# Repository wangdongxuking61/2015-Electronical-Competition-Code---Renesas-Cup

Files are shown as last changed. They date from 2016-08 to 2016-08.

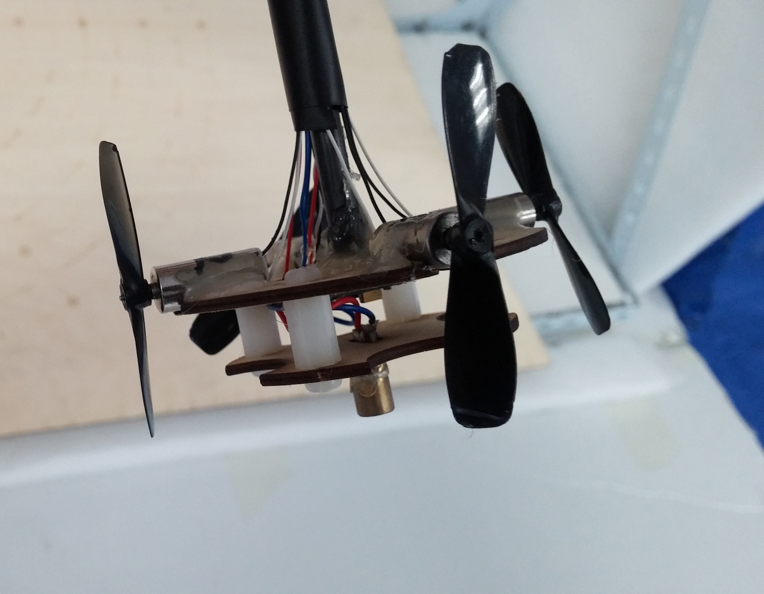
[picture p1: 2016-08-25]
pictures/CAM00127.jpg

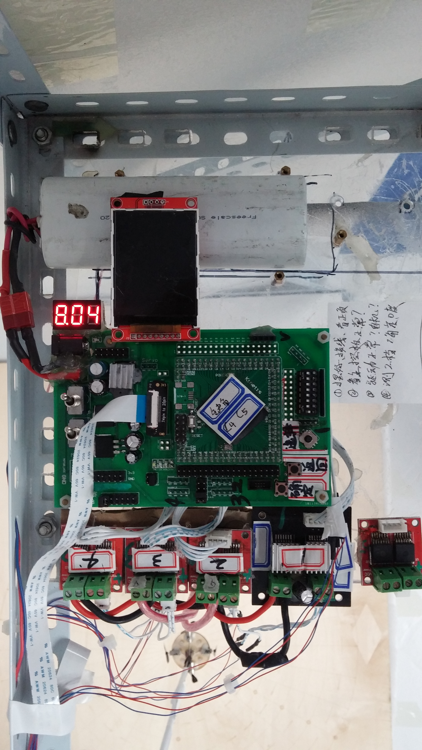
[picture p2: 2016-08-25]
pictures/CAM00123.jpg

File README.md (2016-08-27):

# 2015年全国大学生电子设计竞赛“瑞萨杯”队伍开源硬件&代码<p>

### 作品简介
* 捧杯题目：B题风力摆<p>
* 捧杯学校：大连理工大学<p>
* 总结帖：http://www.znczz.com/thread-237701-1-1.html<p>
* 作品展示视频：http://v.youku.com/v_show/id_XMTY5OTcxODE1Mg==.html?beta&<p>
* 谈情怀、技术、公平性等撕逼话题，请转：http://www.znczz.com/thread-105261-1-1.html<p>
* 硬件组成：K60单片机、MPU6050、空心杯电机、BTS79XX系列驱动芯片、山外（原鹰眼）二值化摄像头等<p>

### 目录简介<p>
* 2015-Electronical-Competition-Code：比赛代码工程，使用IAR7.3打开<p>
* 2015 Electronical Competition Hardware Board：比赛硬件工程，含原理图和PCB，使用Altium Designer2014打开<p>
* CAD：使用激光雕刻机制作的托盘支架等部件工程图，使用AutoCAD打开<p>
* 相关资料：相关介绍资料和器件资料<p>
* pictures：作品的一些照片<p>
* 风力摆控制系统(B题)2015电子设计大赛.pdf：赛题B题目要求<p>
* 2015电赛瑞萨杯-B题经验总结-王东旭.pdf：赛后总结，执笔人王东旭<p>

### 上位机<p>
* 做关于硬件的比赛肯定少不了上位机的辅助，然而一个好的上位机简直是利器<p>
* 智能车超好用上位机推荐(附C#教程)：http://www.znczz.com/thread-237704-1-1.html<p>
* 自己开发的上位机源码：https://github.com/wangdongxuking61/C-sharp_PC2MCU_Draw<p>

### 执笔人简介（欢迎技术交流）：<p>
* 本硕学校：大连理工&国防科大<p>
* wechat：wangdongxuking61<p>
* 擅长&爱好：C/C++、硬件、SDN、摄影<p>

### 有空完善完善...<p>

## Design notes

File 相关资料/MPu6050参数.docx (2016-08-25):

Mpu6050为全球首例整合3轴陀螺仪、3轴加速器、含9轴融合演；MPU-6000为全球首例整合性6轴运动处理组件，相较于多组件方案，免除了组合陀螺仪与加速器时之轴间差的问题，减少了大量的包装空间。MPU-6000整合了3轴陀螺仪、3轴加速器，并含可藉由第二个I2C端口连接其他厂牌之加速器、磁力传感器、或其他传感器的数位运动处理(DMP: Digital Motion Processor)硬件加速引擎，由主要I2C端口以单一数据流的形式，向应用端输出完整的9轴融合演算技术InvenSense的运动处理资料库，可处理运动感测的复杂数据，降低了运动处理运算对操作系统的负荷，并为应用开发提供架构化的API。
MPU-6000的角速度全格感测范围为±250、±500、±1000与±2000°/sec (dps)，可准确追緃快速与慢速动作，并且，用户可程式控制的加速器全格感测范围为±2g、±4g±8g与±16g。产品传输可透过最高至400kHz的I2C或最高达20MHz的SPI。

MPU-6000可在不同电压下工作，VDD供电电压介为2.5V±5%、3.0V±5%或3.3V±5%，逻辑接口VVDIO供电为1.8V± 5%。MPU-6000的包装尺寸4x4x0.9mm(QFN)，在业界是革命性的尺寸。其他的特征包含内建的温度感测器、包含在运作环境中仅有±1%变动的振荡器。

应用：运动感测游戏；现实增强；电子稳像 (EIS: Electronic Image Stabilization)
　　　　　 光学稳像(OIS: Optical Image Stabilization)；行人导航器；“零触控”手势用户接口；姿势快捷方式
认证市场：智能型手机；平板装置设备；手持型游戏产品；游戏机；3D遥控器；可携式导航设备
特征
　　1、以数字输出6轴或9轴的旋转矩阵、四元数(quaternion)、欧拉角格式(Euler Angle forma)的融合演算数据。
　　2、具有131 LSBs/°/sec 敏感度与全格感测范围为±250、±500、±1000与±2000°/sec 的3轴角速度感测器(陀螺仪)。
　　3、可程式控制，且程式控制范围为±2g、±4g、±8g和±16g的3轴加速器。
　　4、移除加速器与陀螺仪轴间敏感度，降低设定给予的影响与感测器的飘移。
　　5、数字运动处理(DMP: Digital Motion Processing)引擎可减少复杂的融合演算数据、感测器同步化、姿势感应等的负荷。
　　6、运动处理数据库支持Android、Linux与Windows
　　7、内建之运作时间偏差与磁力感测器校正演算技术，免除了客户须另外进行校正的需求。
　　8、以数位输出的温度传感器
　　9、以数位输入的同步引脚(Sync pin)支援视频电子影相稳定技术与GPS
　　10、可程式控制的中断(interrupt)支援姿势识别、摇摄、画面放大缩小、滚动、快速下降中断、high-G中断、零动作感应、触击感应、摇动感应功能。
　　11、VDD供电电压为2.5V±5%、3.0V±5%、3.3V±5%；VDDIO为1.8V± 5%
　　12、陀螺仪运作电流：5mA，陀螺仪待命电流：8A；加速器运作电流：8A，加速器省电模式电流： 8A@10Hz
　　13、高达400kHz快速模式的I2C，或最高至20MHz的SPI串行主机接口(serial host interface)
　　14、内建频率产生器在所有温度范围(full temperature range)仅有±1%频率变化。
　　15、使用者亲自测试
　　16、10,000 g 碰撞容忍度
　　17、为可携式产品量身订作的最小最薄包装 (4x4x0.9mm QFN)
　　18、符合RoHS及环境标准MPU-6000为全球首例整合性6轴运动处理组件，相较于多组件方案，免除了组合陀螺仪与加速器时之轴间差的问题，减少了大量的包装空间。MPU-6000整合了3轴陀螺仪、3轴加速器，并含可藉由第二个I2C端口连接其他厂牌之加速器、磁力传感器、或其他传感器的数位运动处理(DMP: Digital Motion Processor)硬件加速引擎，由主要I2C端口以单一数据流的形式，向应用端输出完整的9轴融合

演算技术：InvenSense的运动处理资料库，可处理运动感测的复杂数据，降低了运动处理运算对操作系统的负荷，并为应用开发提供架构化的API。
　从MPU6050的技术文档里我们可以看得出来一些重要参数出来！如果比例数是多少，芯片的特性都是可以看得出来的！

第一张是MPU6000与MPU6050芯片的比较！

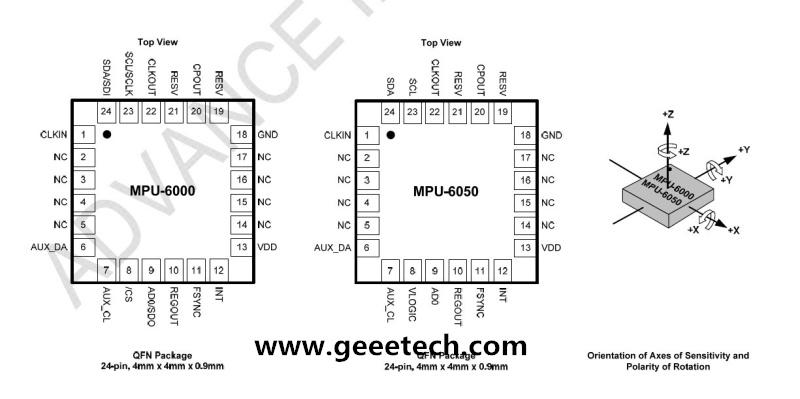
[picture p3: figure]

第二张是MPU6000与MPU6050芯片的最小驱动电路的连接!

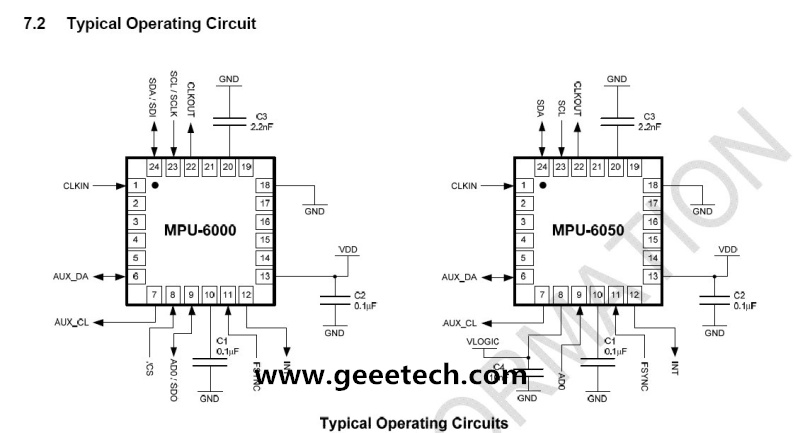
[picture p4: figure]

第三张是陀螺仪的设计规范表格！

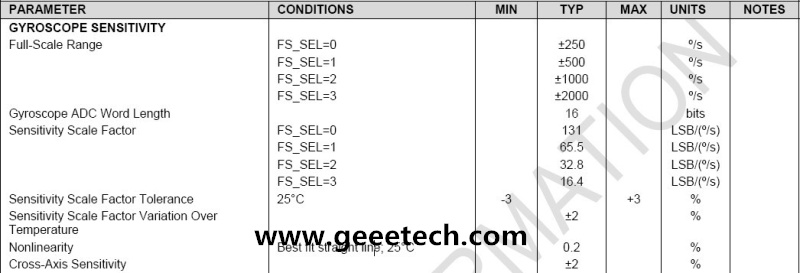
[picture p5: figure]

第四张是加速度的设计规范表格！

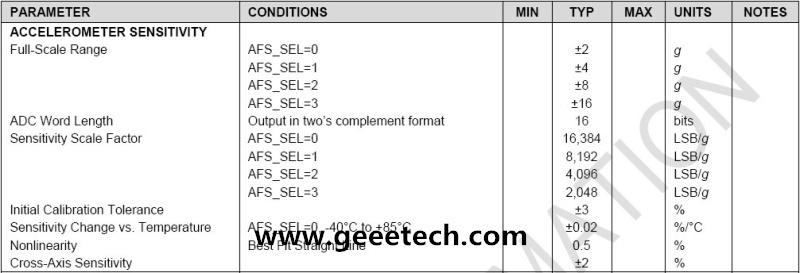
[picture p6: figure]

下面是arduino与MPU6050的小模块的连线图：
　　A4接SDA A5接SCL vcc接3v3商家说可以接5v但是保守起见还是接了3.3v GND接GND不过mpu受温度的影响精度相差比较大！
　　注意：本模块采用的是IIC通信方式，所以我们只需要连接四跟线就可以完成电路的连接，简单方便！
1.关于6050 陀螺仪和加速度计 的角速度和角度计算。
　　A.陀螺仪角度计算，很多帖子中都提到了用的是积分，但是我这里还是重新讲下。
　　　　　　angle_n = angle_n-1 + (Gyro-C_Gyro)*R_Gyro;
　　　　　　　　（1）angle_n 当前角度值，它的单位是度（°）
　　　　　　　　（2）angle_n-1 上一次计算出的角度值
　　　　　　　　（3）Gyro 陀螺仪敏感轴偏转值，也就是当前敏感轴读数
　　　　　　　　（4）C_Gyro 陀螺仪零点偏移值，这个值的测量方法是：将陀螺仪敏感轴水平放置静止时的读数，我的零点偏移值是水平、垂直、倒置，分别取1024次，作平均值得出的，读数是-177.8865041，但是最后在程序实践中，调整到-99.90。或许还有别的办法，自己看着办吧。
　　　　　　　　（5）R_Gyro 是陀螺仪比例。飞思卡尔的参考中提到这个值是可以计算出来的，下面我会提供下载，大家自己去看看怎么算的，但是在其论坛和调试手册中都提到，这个比例值还是实验法测量出来的比较准确。
B.加速度仪 角度计算。
　　 加速度仪的角度计算有很多方法，论坛里就有2中。但是都用到了三角函数，数学没学好，照抄了也不行。参考了飞思卡尔的计算方法后大概是这样的。
Angle_Z = (az-C_Z)*R_Z;
　　　　　　　　 （1）angle_z 加速度计敏感轴Z轴产生倾角计算出的角度，单位度（°）
　　　　　　　　 （2）az 是加速度仪 Z轴读数
　　　　　　　　 （3）C_Z Z轴零点偏移量 测量方法和陀螺仪的一样。
　　　　　　　　 （4）R_Z 加速度计Z轴比例
　　C.反复试验，MPU6050加速度计Z轴对应的是陀螺仪的X轴。不知道是不是我的有问题，还是就这么设计的？

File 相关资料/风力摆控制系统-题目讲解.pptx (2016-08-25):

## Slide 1

电子设计竞赛
控制类题目讲解

## 1、全国电子设计竞赛简介 2、控制类题目注意事项 3、2015年风力摆控制系统——硬件 4、2015年风力摆控制系统——机械 5、2015年风力摆控制系统——软件

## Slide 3

全国电子设计竞赛简介

- 大学生重点赛事
- 两年一届
- “半封闭，相对集中”的比赛方式
- 为期4天（第一天8:00 ~ 第四天20:00）
- 提交竞赛报告

东北赛区赛
综合测评
全国复测

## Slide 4

控制类题目注意事项

1、赛前准备
硬件：
  - 主控板（含有所有功能）
  - 驱动模块（BTS即可）
  - 传感器（加速度计，陀螺仪，绝对编码器，相对编码器， 霍尔测速传感器，CCD，摄像头，光电管，等等）
  - 蓝牙模块（至少一对）
  - 显示屏
  - 电机
  - 官网提供主要元器件清单（猜题目）
  - 个人备用元件
软件：
  - UI
  - 对应硬件的软件（电机驱动、传感器驱动、测速，等等）
2、认真审题（第一天）
3、确定方案（多测试）

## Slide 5

风力摆控制系统——硬件

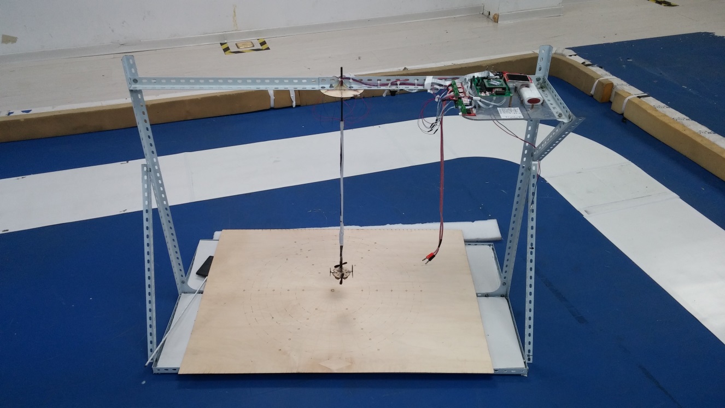
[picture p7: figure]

风力摆控制系统

主控芯片K60

显示屏

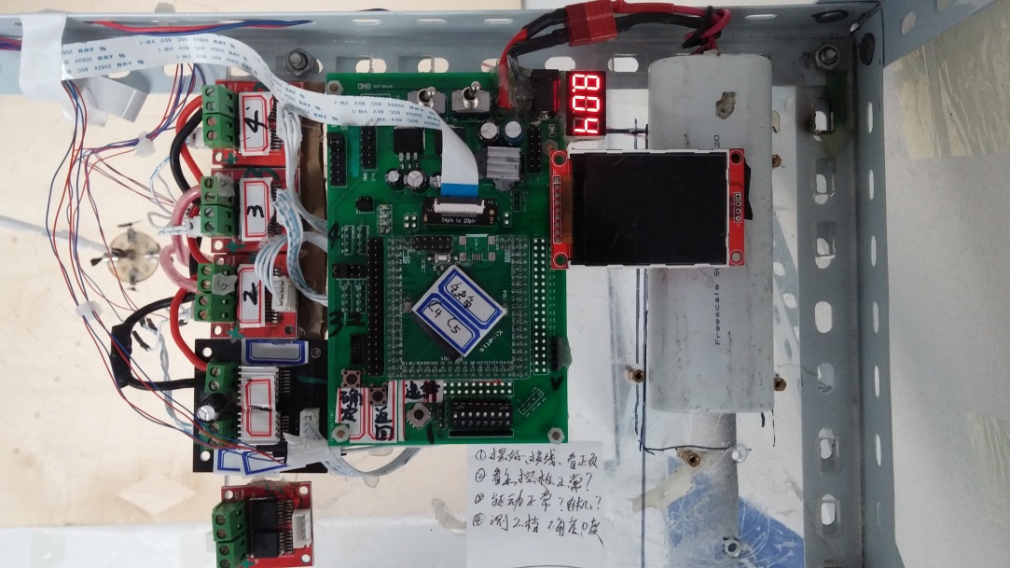
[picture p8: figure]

四路驱动模块

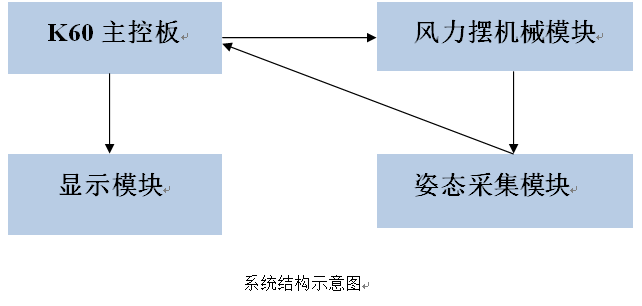
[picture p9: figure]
屏幕剪辑

主控板

备用驱动模块

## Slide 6

风力摆控制系统——硬件

主控芯片方案 ——飞思卡尔K60
电源方案 ——LM2596 (5v)，AMS1117(3v)
驱动方案 ——BTN7971
电机方案 ——四轴空心杯电机
传感器方案 ——陀螺仪加速度计MPU6050

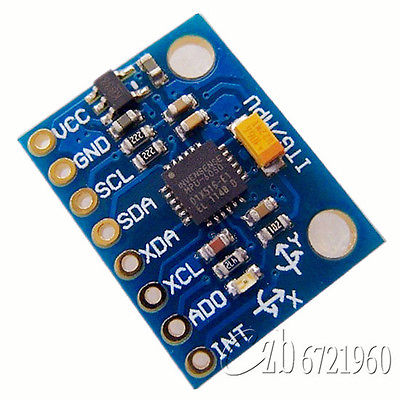
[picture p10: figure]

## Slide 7

风力摆控制系统——机械

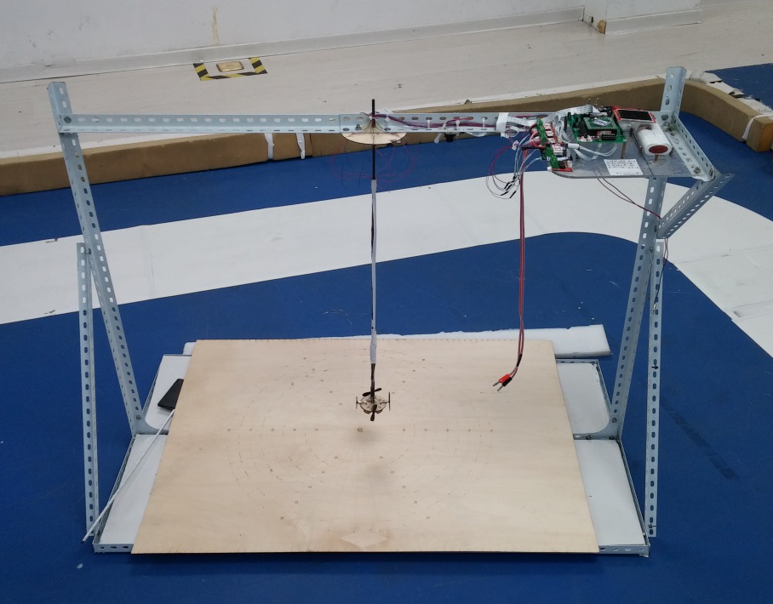
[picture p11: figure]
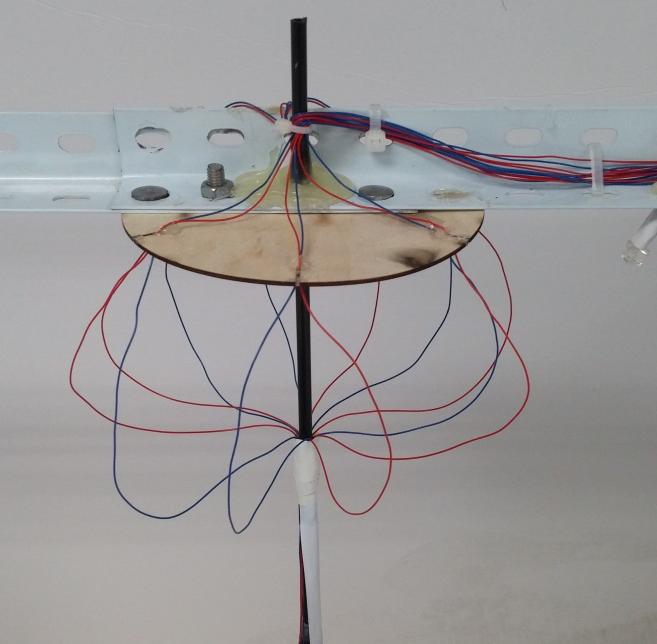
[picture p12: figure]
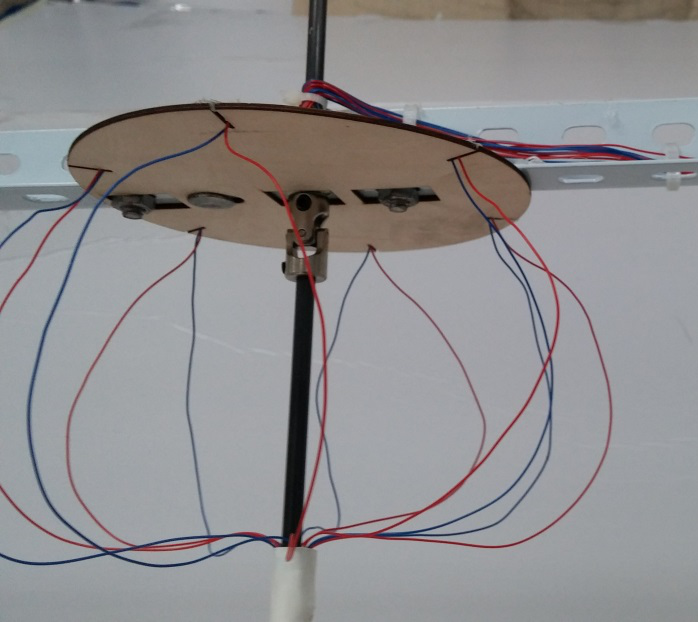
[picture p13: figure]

细导线
——减少外力对摆的干扰
导线托盘
——使摆的受力均匀

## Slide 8

风力摆控制系统——机械

风力摆摆头

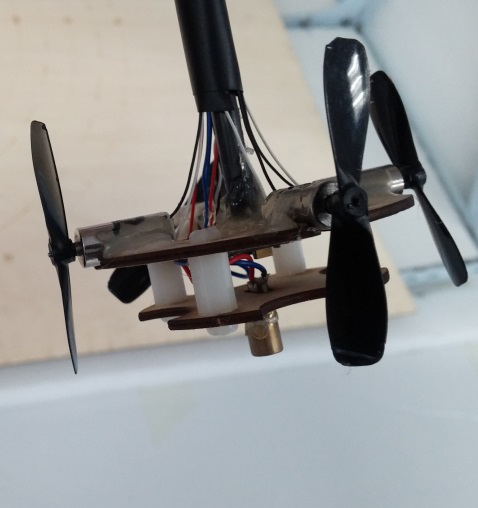
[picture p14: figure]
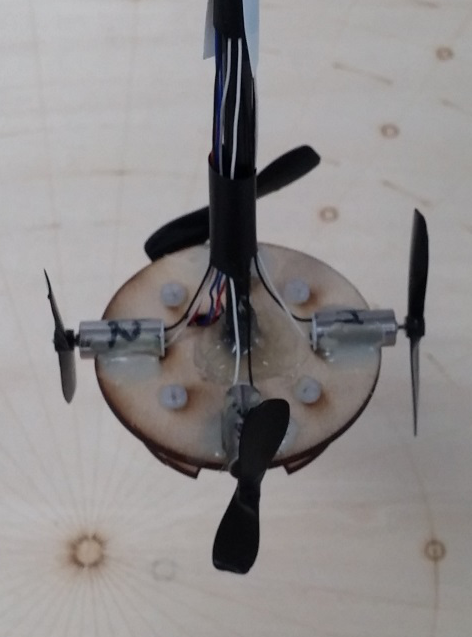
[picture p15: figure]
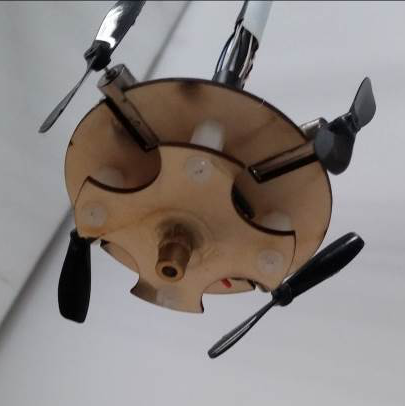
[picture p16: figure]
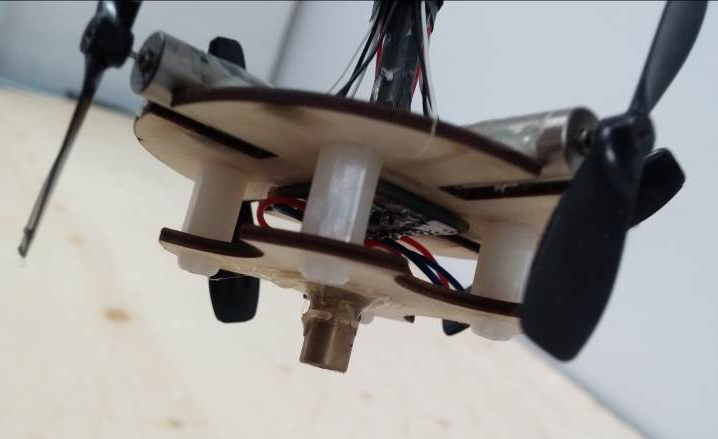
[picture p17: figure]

两个激光雕刻托盘，上大下小，上面固定电机，中间放角度传感器MPU6050，下面固定激光头。

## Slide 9

风力摆控制系统——软件

（1）风力摆算法分析
（2）核心：PID

## （1）风力摆算法分析

单摆做简谐运动的周期跟摆长的平方根成正比，跟重力加速度的平方根成反比，跟振幅、单摆的质量无关。

T=2π√(L/g)

实测自然摆动的周期，单摆每次摆动只是损失很少能量，所以只要每个周期pid控制电机调整，补给亏损能量，据能量守恒定律，单摆将持续等幅摆动。

## （1）风力摆算法分析

画圆：
x方向单摆按照sin变化，y方向单摆按照cos变化，使两方向周期相位相差90°，风摆将照圆形轨迹运动。

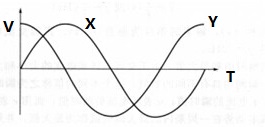
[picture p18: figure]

## （2）简单速度PID调节

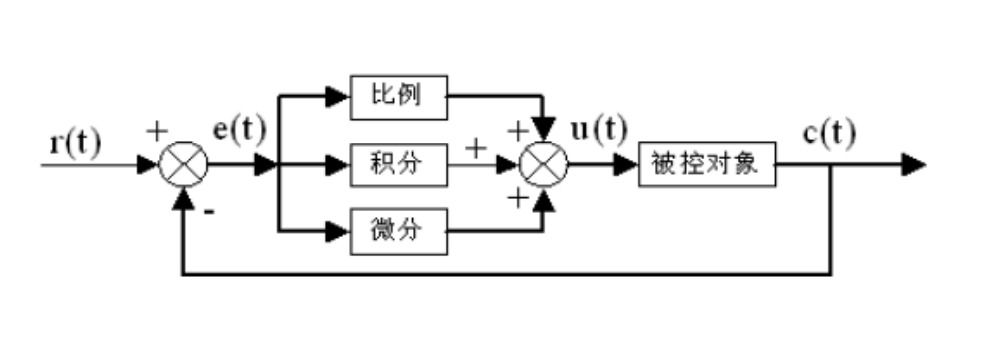
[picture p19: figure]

## 参考代码

//采集，更新
speednow =脉冲累加器;//在此省略方向读取
errornow = goalspeed - speednow ;
error_I=error_I+errornow;//累计误差
error_d=speednow-speedold;
//控制输出
p_data=(long int)(p_speed)*errornow;
i_data=(long int)(i_speed)*error_I;
d_data=(long int)(d_speed)*error_d;
If(i_data> i_data_max)
i_data= i_data_max;
Else if(i_data< i_data_min)
i_data= i_data_min; //积分限幅
givenpwm=p_data+i_data+d_data;
pwm输出;//包括正反转判断，还有限幅
//存储历史值
speedold=speednow;

## 比例参数KP的作用

- 是加快系统的响应速度，提高系统的调节精度。随着KP的增大系统的响应速度越快，系统的调节精度越高，但是系统易产生超调，系统的稳定性变差，甚至会导致系统不稳定。KP取值过小，调节精度降低，响应速度变慢，调节时间加长，使系统的动静态性能变坏。

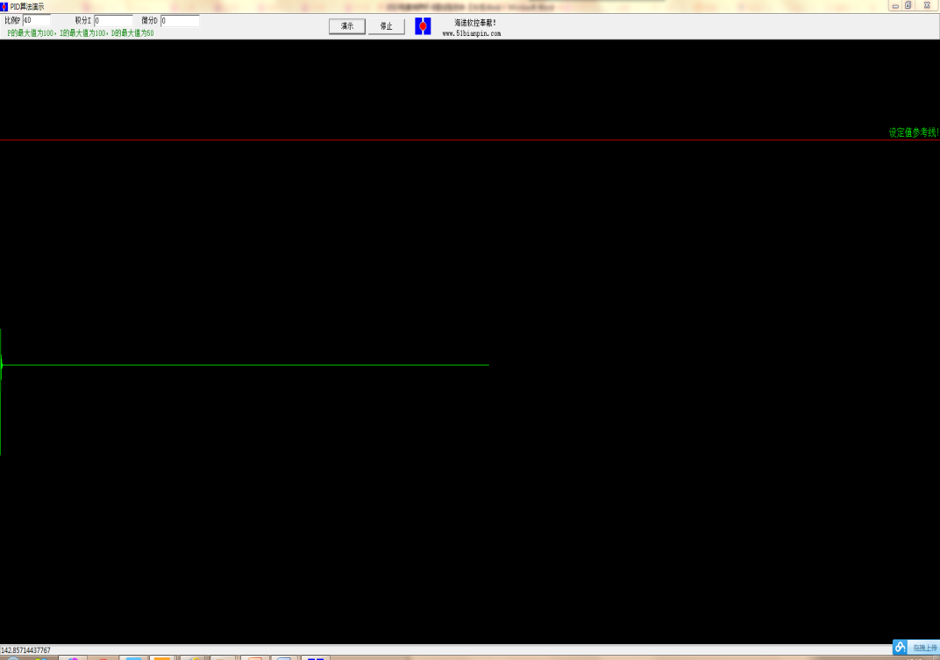
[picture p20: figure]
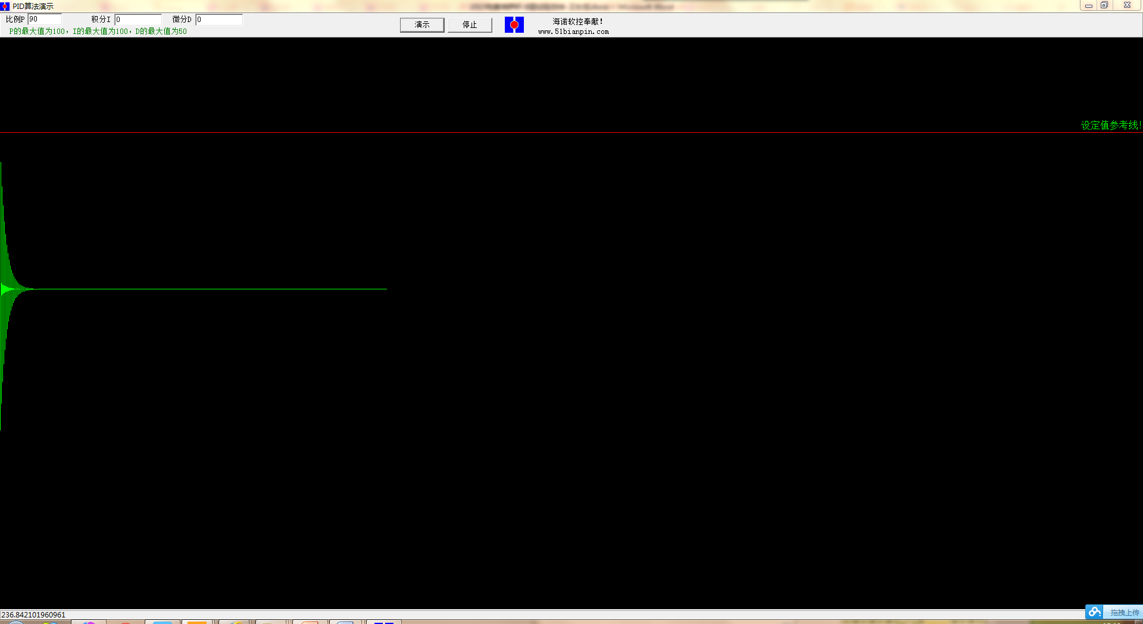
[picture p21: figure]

P=50

P=90

## 积分作用参数Ti

- 最主要作用是消除系统的稳态误差。Ti越大系统的稳态误差消除的越快，但Ti也不能过大，否则在响应过程的初期会产生积分饱和现象。若Ti过小，系统的稳态误差将难以消除，影响系统的调节精度。另外在控制系统的前向通道中只要有积分环节总能做到稳态无静差。从相位的角度来看一个积分环节就有90° 的相位延迟，也许会破坏系统的稳定性。

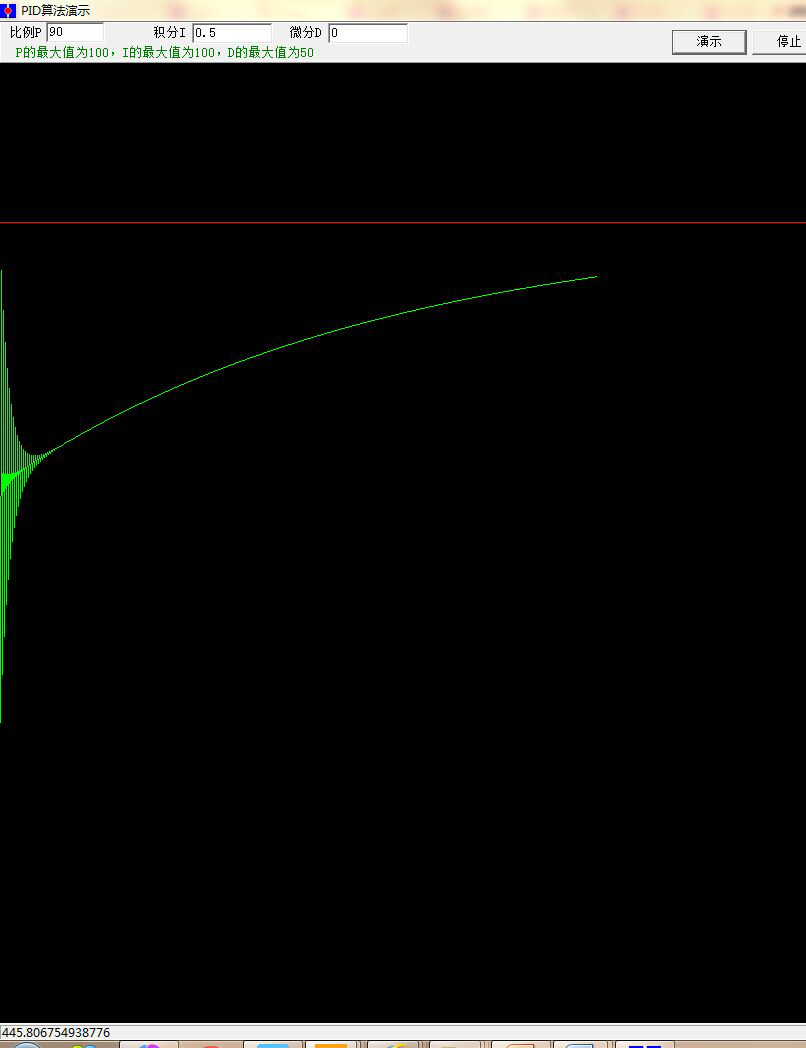
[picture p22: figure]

P=90 I=0.5

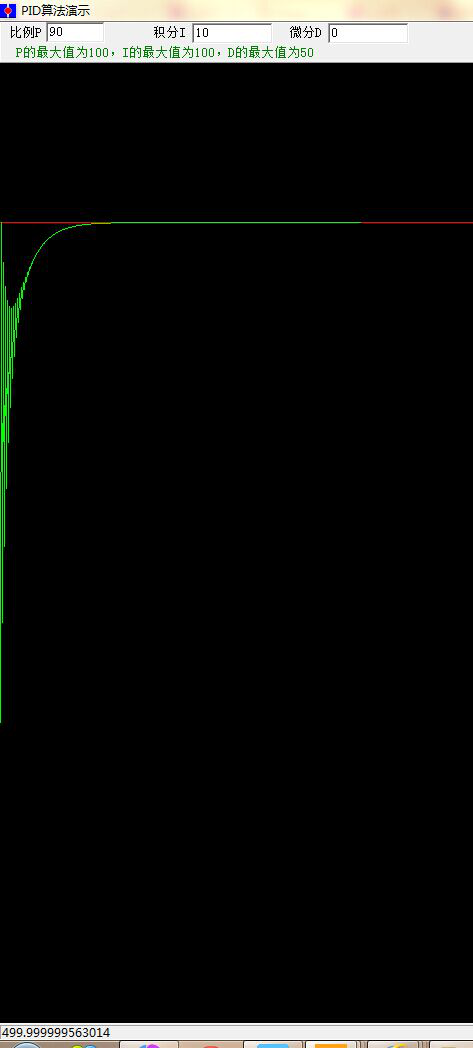
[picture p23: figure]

P=90 I=10

## 微分作用参数D

- 微分作用参数D的作用是改善系统的动态性能，其主要作用是在响应过程中抑制偏差向任何方向的变化，对偏差变化进行提前预报。但Ti不能过大，否则会使响应过程提前制动，延长调节时间，并且会降低系统的抗干扰性能。

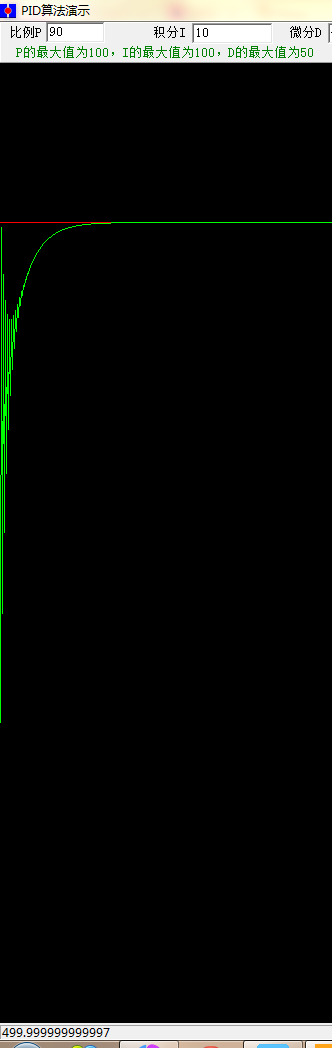
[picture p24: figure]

P=90 I=10 D=-1

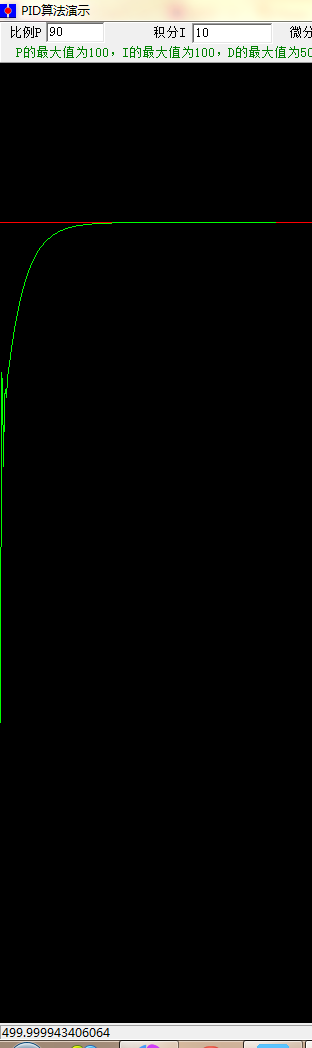
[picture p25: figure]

P=90 I=10 D=-30

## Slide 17

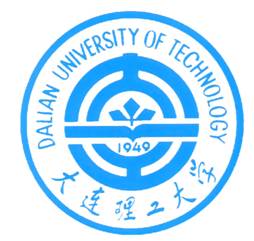
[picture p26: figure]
图片1

Thank you!

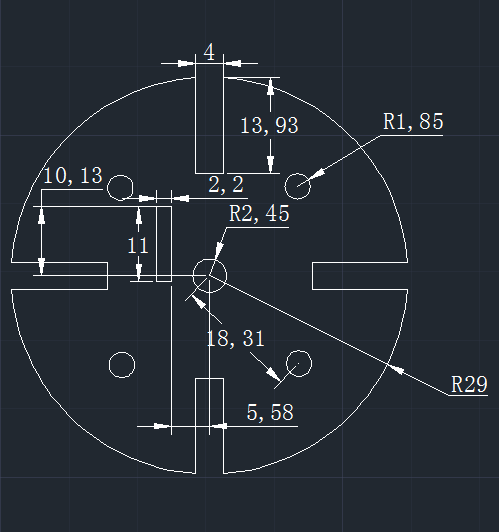
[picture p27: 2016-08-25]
pictures/底座_上.png

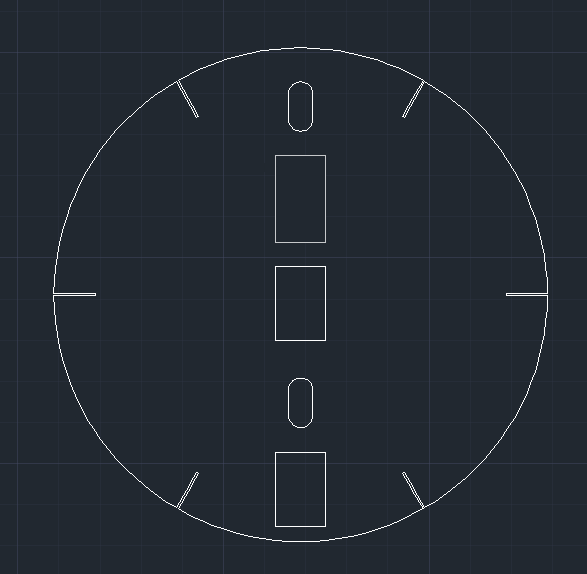
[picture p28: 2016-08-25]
pictures/圆盘.png

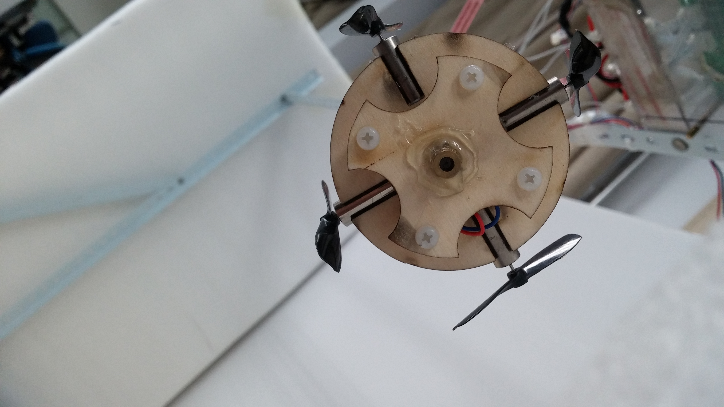
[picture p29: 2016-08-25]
pictures/CAM00130.jpg

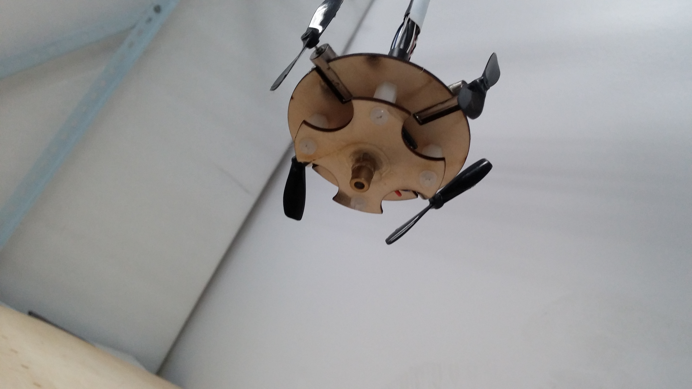
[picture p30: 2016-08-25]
pictures/CAM00129.jpg

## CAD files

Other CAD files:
CAD/坐标板（带圈）.dwg
CAD/工作台.dwg
CAD/电机支架&激光支架.dwg
CAD/圆盘.dwg

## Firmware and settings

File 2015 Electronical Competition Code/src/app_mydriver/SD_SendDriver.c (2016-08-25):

#include"include.h"
/******************** (C) COPYRIGHT 2011 野火嵌入式开发工作室 ********************
 * 文件名       ：OwnSD_Driver.c
 * 描述         ：所有模块初始化代码
 * 实验平台     ：凌立印象开发板
 * 库版本       ：基于野火库
 * 嵌入系统     ：
 * 作者         ：xuxu
**********************************************************************************/ 


FIL fdst;  //文件
FATFS fs;  //文件系统
UINT bw;
unsigned char Send_Img[81];
unsigned int add=0;
static unsigned char Sd_writeOnce=0;
unsigned char SD_enable=0;
static unsigned int flash_write_count=0;
#define write_count_max 2240  //2240/75=29.8s 75为1s帧数 


/************************************************
*  函数名称：SDcard_Init
*  功能说明：SD卡初始化（使用K60自带的SD模块）
*  参数说明：无
*  函数返回：无
*  修改时间：2014-1-14    已经测试
*************************************************/
void SDcard_Init()
{
    FIL fdst;  //文件
    FATFS fs;  //文件系统
    int res;
    char *str = "感谢您选用 野火Kinetis开发板 ！^_^ ";
    f_mount(0, &fs);	//SD卡系统初始化
    res = f_open(&fdst, "\\FireDemo.txt", FA_OPEN_ALWAYS | FA_WRITE | FA_READ);  //打开文件，如果没有就创建，带读写打开
    if( res == FR_DISK_ERR)
    {
        printf( "\n没插入SD卡？？\n" );
    }
    else if ( res == FR_OK )
    {
        printf( "\n文件打开成功 \n" );
    }
    else
    {
        printf("\n返回值异常");
    }
    f_puts(str, &fdst);
    f_close(&fdst);//关闭文件 
}



   
   
/*************************************************************************
*  函数名称：SD_Writedata
*  功能说明：
*  参数说明：
*  函数返回：无
*  修改时间：2012-2-14    已测试
*************************************************************************/
void SD_Writedata()
{
    //存单个图像
    static int SECTOR_NUM=0;
    static unsigned int H,L,write_data = 0;
    static unsigned char data8; 
    static unsigned int data32;
    static short int wH,wL;
    
    //仅仅存一幅图像
    /*if(Sd_writeOnce==0)//write flash
    {
        LCD_PutString(0,60,"SD start write!!!",Red,Green);
        //停车
        Sd_writeOnce = 1;
        //操作
        f_mount(0, &fs);	//SD卡系统初始化
        f_open(&fdst, "\\data.txt", FA_OPEN_ALWAYS | FA_WRITE | FA_READ);  //打开文件，如果没有就创建，带读写打开
    }
    if(Sd_writeOnce == 1)
    {
        Sd_writeOnce = 2;
        for(int j=0;j<240;j++)
        {
            for(int i=0,ii=0;i<40;i++)
            {
                Send_Img[ii++] = ((((unsigned int)(Image_fire[j][i]))&0xf0)>>4) + 'a';
                Send_Img[ii++] = (((unsigned int)(Image_fire[j][i]))&0x0f) + 'a';
            }
            Send_Img[80]='\n';
            f_write(&fdst,Send_Img,81,&bw);
        }
        LCD_PutString(0,60,"SD write finish!!!",Red,Green);
        f_close(&fdst);//关闭文件 
    }
     return;  */
        
        
    //初始化
    if(Sd_writeOnce==0)//write flash
    {
        #define Send_hang 150
        //Image_fire[Send_hang]
        SECTOR_NUM = flash_write_count/32;
        add = (flash_write_count%32)*64;
        flash_write_buf(186 + SECTOR_NUM,add,40,Image_fire[Send_hang]);
        
        //Time_1ms
        //centre[Send_hang]
        H = (unsigned int)(Time_1ms);
        L = (unsigned int)(centre[Send_hang]);
        write_data = (H<<16) + L;
        flash_write(186 + SECTOR_NUM,add + 40,write_data);
        
        //black_L[Send_hang]
        //black_R[Send_hang]
        H = (unsigned int)(black_L[Send_hang]);
        L = (unsigned int)(black_R[Send_hang]);
        write_data = (H<<16) + L;
        flash_write(186 + SECTOR_NUM,add + 44,write_data);
        
        //halfwidth[Send_hang]
        //Angle.m_angle
        H = (unsigned int)(halfwidth[Send_hang]);
        L = (unsigned int)((int)(Angle.m_angle*10));
        write_data = (H<<16) + L;
        flash_write(186 + SECTOR_NUM,add + 48,write_data);
        
        //Angle.G_angle
        //Speed.Car
        H = (unsigned int)((int)(Angle.G_angle*10));
        L = (unsigned int)((int)(Speed.Car));
        write_data = (H<<16) + L;
        flash_write(186 + SECTOR_NUM,add + 52,write_data);
        
        //Direction.Gyro
        //Angle.PWM
        H = (unsigned int)((int)(Direction.Gyro));
        L = (unsigned int)((int)(Angle.PWM));//all_PWM_L
        write_data = (H<<16) + L;
        flash_write(186 + SECTOR_NUM,add + 56,write_data);
        
        //Speed.PWM
        //Speed.PWM_Integral
        H = (unsigned int)((int)(Speed.PWM));//all_PWM_R
        L = (unsigned int)((int)(Speed.PWM_Integral));
        write_data = (H<<16) + L;
        flash_write(186 + SECTOR_NUM,add + 60,write_data);
        
        flash_write_count++;
        if(flash_write_count >= write_count_max)
           Sd_writeOnce = 1;
    }
    else if(Sd_writeOnce==1 && StartLine.flag==1 && Time_1ms>StartLine.time_record + StartLine.Delaytime + 1)//read flash and write SD
    {
        //界面
        _LED4 = 0;
        LCD_PutString(0,80,"SD start write!!!",Red,Green);
        //操作
        f_mount(0, &fs);	//SD卡系统初始化
        f_open(&fdst, "\\data.txt", FA_OPEN_ALWAYS | FA_WRITE | FA_READ);  //打开文件，如果没有就创建，带读写打开
        for(int SECTOR_count = 186;SECTOR_count <= 255;SECTOR_count++)
        {
            for(int in_count = 0;in_count < 32;in_count++)
            {
                int read_add = in_count * 64;
                for(int i=0,ii=0;i<40;i++)
                {
                    data8 = flash_read(SECTOR_count, read_add + i,uint8);
                    Send_Img[ii++] = ((((unsigned int)(data8))&0xf0)>>4) + 'a';
                    Send_Img[ii++] = (((unsigned int)(data8))&0x0f) + 'a';
                }
                f_write(&fdst,Send_Img,80,&bw);
                for(int i=40;i<64;i+=4)
                {
                    data32 = flash_read(SECTOR_count,read_add + i,uint32);	//读取4字节
                    wH = (short int)(data32>>16);
                    wL = (short int)(data32&0x0000ffff);
                    f_printf(&fdst, " %d", wH);
                    if(i==60)
                        f_printf(&fdst, " %d\n", wL);
                    else
                        f_printf(&fdst, " %d", wL);
                }
            } 
        }
        f_close(&fdst);//关闭文件 
        Sd_writeOnce = 2;
        LCD_PutString(0,80,"SD write finish!!!",Red,Green);
    }
    else if(Sd_writeOnce ==2)
    {
        _LED4 = (Time_1ms/500)%2;
        return;
    }
}

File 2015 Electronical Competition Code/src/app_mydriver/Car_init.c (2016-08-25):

#include"include.h"




/************************************************
*  函数名称：System_Init
*  功能说明：系统所有功能初始化函数
*  参数说明：无
*  函数返回：无
*  修改时间：2014-1-14    no测试
*************************************************/
void System_Init()
{
    //buzzer初始化
    gpio_init(PORTC,14, GPO, LOW);
    Buzzer_Ring_ms(100);

    
    //LED:全灭
    gpio_init(PORTE,24, GPO, HIGH);
    gpio_init(PORTE,25, GPO, HIGH);
    gpio_init(PORTE,26, GPO, HIGH);
    
    
    //做时间测试
    gpio_init(PORTE,28, GPO, LOW);
    //紧急停车指令接口
    //gpio_init(PORTE,8, GPI, LOW);
        
    
    //LCD模块初始化
    LCD_init(TRUE);    //TRUE  和 FALSE是正着还是反着刷屏 
    Disp_single_colour(Yellow);//Black
    //Print_child();    //小破孩刷屏
    
    //拨码开关端口初始化
    Switch_init();
    //重要参数初始化
    Parameters_init_CAR();

    
    //串口初始化
    uart_init(UART0,115200);
    uart_irq_DIS(UART0);//(比赛要DIS，不能是EN)
    
    
//    //CCD初始化
//    adc_init(ADC0, SE8);//PB0
//    gpio_init(PORTB, 1, GPO, LOW);
//    gpio_init(PORTB, 2, GPO, LOW);
    
    
    //1ms的定时器
    pit_init_ms(PIT0, 1);
    set_irq_priority(68,1);
    enable_irq(68);
    
    
    MPU6050_Init(1000,42);
    /*    
    //初始化陀螺仪L3G4200D,初始化加速度计mma8451
    static unsigned char ID1,ID2;
    Init_L3G4200D();//11010011	
    ID1 = Single_Read(L3G4200_Addr,WHO_AM_I);
    MMA845x_init();//00011010
    ID2 = Single_Read(MMA845x_IIC_ADDRESS,WHO_AM_I_REG);
    if(ID1 == 0xD3 && ID2==0x1A)
    {
        LCD_PutString(0,120,"L3G + MMA OK!",Red,Green);
        //printf("IIC OK!!!");
    }
    else
    {
        //printf("IIC ERROR!!!");
    }
    */
    
    //pwm模块,编码器测速初始化
    Pwm_Port_init();
    //Decoder_init();
    //SSI_Init();
    
    //按键
    exti_init(PORTB, 8,falling_up);    //按键中断，下降沿触发中断
    exti_init(PORTB, 6,falling_up);    //按键中断，下降沿触发中断
    exti_init(PORTB, 9,falling_up);    //按键中断，下降沿触发中断
    exti_init(PORTB,10,falling_up);    //按键中断，下降沿触发中断
    exti_init(PORTB, 7,falling_up);    //按键中断，下降沿触发中断
    exti_init(PORTB, 5,falling_up);    //按键中断，下降沿触发中断
    exti_init(PORTB, 3,falling_up);    //按键中断，下降沿触发中断
    set_irq_priority(88,2);
    enable_irq(88); 			//打开PTB的中断

    
    //结束初始化
    delayms(100);
    Buzzer_Ring_ms(100);
}



/************************************************
*  函数名称：Parameters_init_CAR2
*  功能说明：重要变量初始化(CAR2)
*  参数说明：无
*  函数返回：无
*  修改时间：2014-1-14    已经测试
*************************************************/
void Parameters_init_CAR()
{
    for(int loop=1;loop<=7;loop++)
    {
        Mode.para[loop][0] = 100;//P
        Mode.para[loop][1] = 3;  //I
        Mode.para[loop][2] = 52; //D
        Mode.para[loop][3] = 30; //Length适用于第二问，Dir适用于第三问
        Mode.I_max = 2800;
    }
    
    //摆动的周期
    Angle.Period = 1500;
     //DIR为第三问
    Mode.para[3][3] = 0;
    //第五问
    Mode.para[5][3] = 30;
    
    //偏差矫正
    Angle.DirErr[0] = 0;
    Angle.DirErr[1] = 1.6;
    Angle.DirErr[2] = 2.5;
    Angle.DirErr[3] = 2.5;
    Angle.DirErr[4] = 2.0;
    Angle.DirErr[5] = 1.0;
    Angle.DirErr[6] = 0.5;
    Angle.DirErr[7] = 0;
    Angle.DirErr[8] = -1;
    Angle.DirErr[9] = 1.0;
    Angle.DirErr[10] = 2.0;
    Angle.DirErr[11] = 2.0;
    Angle.DirErr[12] = 1.5;
    Angle.DirErr[13] = 0.3;
    Angle.DirErr[14] = 0;
    Angle.DirErr[15] = -1.5;
    Angle.DirErr[16] = -1.5;
    Angle.DirErr[17] = -2.0;
    
    for(int loop=0;loop<=17;loop++)
        Angle.DirErr[loop+18] = Angle.DirErr[loop];
        
    //第二问设置的力度
    /************************ LLLLLLLLL ********************/
    Angle.ForceL[30] = 30.0;//
    Angle.ForceL[32] = 31.7;//
    Angle.ForceL[34] = 33.4;//
    Angle.ForceL[36] = 35.0;//
    Angle.ForceL[38] = 36.6;//
    
    Angle.ForceL[40] = 38.2;//
    Angle.ForceL[42] = 39.9;//
    Angle.ForceL[44] = 41.8;//
    Angle.ForceL[46] = 43.5;//
    Angle.ForceL[48] = 45.0;//
    
    Angle.ForceL[50] = 46.9;//46.5
    Angle.ForceL[52] = 48.2;//
    Angle.ForceL[54] = 49.9;//
    Angle.ForceL[56] = 51.4;//
    Angle.ForceL[58] = 52.9;//
    
    Angle.ForceL[60] = 54.2;//
    Angle.ForceL[62] = 55.7;//
    Angle.ForceL[64] = 57.2;//
    Angle.ForceL[66] = 58.9;//
    Angle.ForceL[68] = 60.4;//
    Angle.ForceL[70] = 61.9;//2cm=1.5
    
    /************************ HHHHHHHHHH ********************/
    Angle.ForceH[30] = Angle.ForceL[30];
    Angle.ForceH[32] = Angle.ForceL[32];
    Angle.ForceH[34] = Angle.ForceL[34];
    Angle.ForceH[36] = Angle.ForceL[36];
    Angle.ForceH[38] = Angle.ForceL[38];
    
    Angle.ForceH[40] = Angle.ForceL[40];
    Angle.ForceH[42] = Angle.ForceL[42];
    Angle.ForceH[44] = Angle.ForceL[44];
    Angle.ForceH[46] = Angle.ForceL[46];
    Angle.ForceH[48] = Angle.ForceL[48];
    
    Angle.ForceH[50] = Angle.ForceL[50];
    Angle.ForceH[52] = Angle.ForceL[52];
    Angle.ForceH[54] = Angle.ForceL[54];
    Angle.ForceH[56] = Angle.ForceL[56]; 
    Angle.ForceH[58] = Angle.ForceL[58];//1cm
    
    Angle.ForceH[60] = Angle.ForceL[60];//1.5cm   2cm=1.4
    Angle.ForceH[62] = Angle.ForceL[62];//3cm
    Angle.ForceH[64] = Angle.ForceL[64];//2cm
    Angle.ForceH[66] = Angle.ForceL[66];//2cm
    Angle.ForceH[68] = Angle.ForceL[68];//2cm
    Angle.ForceH[70] = Angle.ForceL[70];//2cm
    
    for(int loop=31;loop<=69;loop+=2)
    {
        Angle.ForceH[loop] = (Angle.ForceH[loop-1] + Angle.ForceH[loop+1])/2.0;
        Angle.ForceL[loop] = (Angle.ForceL[loop-1] + Angle.ForceL[loop+1])/2.0;
    }
}





/************************************************
*  函数名称：Buzzer_Ring_ms
*  功能说明：蜂鸣器叫
*  参数说明：unsigned int n，n为n毫秒
*  函数返回：无
*  修改时间：2014-1-14    已经测试
*************************************************/
void Buzzer_Ring_ms(unsigned int n)
{
    buzzer = 1;
    delayms(n);
    buzzer = 0;
}



/************************************************
*  函数名称：Switch_init
*  功能说明：拨码开关8个引脚初始化
*  参数说明：无
*  函数返回：无
*  修改时间：2014-1-14    已经测试
*************************************************/
void Switch_init()
{
    gpio_init(PORTC, 6, GPI, LOW);
    gpio_init(PORTC, 7, GPI, LOW);
    gpio_init(PORTC, 8, GPI, LOW);
    gpio_init(PORTC, 9, GPI, LOW);
    gpio_init(PORTC,10, GPI, LOW);
    gpio_init(PORTC,11, GPI, LOW);
    gpio_init(PORTC,12, GPI, LOW);
    gpio_init(PORTC,13, GPI, LOW);
}
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

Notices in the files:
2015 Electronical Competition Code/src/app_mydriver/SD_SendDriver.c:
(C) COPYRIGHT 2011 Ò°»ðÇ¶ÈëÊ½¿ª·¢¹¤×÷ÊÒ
